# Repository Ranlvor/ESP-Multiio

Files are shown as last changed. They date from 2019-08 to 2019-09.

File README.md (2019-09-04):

Mechanical
==========

Achtung: Eines der Haltelöscher ist nicht 5mm / 5mm vom Rand entfernt! Das 3D-Druck-Gehäuse geht davon aus, dass alle Löscher 5mm/5mm vom Rand entfernt sind und muss noch angepasst werden.

BOM
===

zwingend Nötig
--------------

Bezeichnung | Beschreibung
------------|--------------
U1          | Wemos D1 Mini

notwendig für LEDs und Schalter
-------------------------------

Bezeichnung                    | Beschreibung                        | Package
-------------------------------|-------------------------------------|-----------------
D1, D2, D3, D4, D5, D6, D7, D8 | LEDs                                | 3mm Through Hole
R1, R2, R3, R4, R5, R6, R7, R8 | Vorwiderstände passend zu den LEDs  | 1206 SMD
U2                             | MCP23017                            | DIP-28
C1                             | Kondensator ca. 100 nF              | 1206 SMD

notwendig für IR receive (getestet, hat nicht funktioniert)
-----------------------------------------------------------

Bezeichnung | Beschreibung                        | Package
------------|-------------------------------------|-----------------
U4          | TL1838                              | TSOP1838
C2          | Kondensator ca. 100 nF              | 1206 SMD
R11         | Widerstand 33 kΩ                    | 1206 SMD
R12         | Widerstand 100 Ω                    | 1206 SMD

notwendig für IR send (ungetestet)
----------------------------------

Bezeichnung | Beschreibung                        | Package
------------|-------------------------------------|-----------------
D-IR1       | IR-LED                              | 3mm Through Hole
Q1          | NPN-Transistor (z.B. BC337)         | TO-92
R10         | Widerstand 53 Ω                     | 1206 SMD
R9          | Widerstand 2.1 kΩ                   | 1206 SMD

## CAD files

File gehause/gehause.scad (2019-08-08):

 
tolerance = 0.3;
layer_hight = 0.2;
epsilon = 0.001;
inf = 100;

roundingRadius = 2;
boardX = 75;
boardY = 68;
boardZ = 1.6;
spaceTop = 15;
spaceBottom = 5;

bottomThickness = 3;
topBottomSplit = 5;
margin = 7;
cableDiameter = 4+2*tolerance;
washerDiameter = 7+2*tolerance;
washerHeight = 1;
screwHeadHeight = 5;
connectionDiameter = 7;
connectionHeight = 2;
cornerOnly = 0;
screwHoleDepth = washerHeight + screwHeadHeight + 6;

cutMode = 0;

mode = [
      0, //top normal Mode
      0, //top infill Mode
      0, //top support block Mode
      0, //top text Mode
      1, //bottom normal mode
      0, //bottom infill mode
];
//$fn = 96;
//$fn=10;

module switch() {
 difference() {
  union() {
    cylinder(h=9,d=6+2*tolerance);
    translate([0,0,9-5]) {
        cylinder(h=1+tolerance,d=12+2*tolerance);
        translate([10/2, -2.5/2-tolerance, -1]) cube([4,2.5+2*tolerance,2+tolerance]);
    };
    translate([-13.2/2-tolerance,-7.9/2-tolerance,-9.5-2*tolerance]) cube([13.2+2*tolerance,7.9+2*tolerance,9.5+2*tolerance]);
    
    translate([-1/2,-2/2,-4-9.5-2*tolerance]) cube([1, 2, 4]);
    translate([-1/2+4.7,-2/2,-4-9.5-2*tolerance]) cube([1, 2, 4]);
    translate([-1/2-4.7,-2/2,-4-9.5-2*tolerance]) cube([1, 2, 4]);
    
    //translate([0,0,9]) cylinder(d=3, h=11);
    translate([0,0,9]) rotate([0,12,0]) cylinder(d=3, h=11);
    translate([0,0,9]) rotate([0,-12,0]) cylinder(d=3, h=11);
  }
  translate([0,0,9-5-layer_hight]) cylinder(h=layer_hight,d=6+2*tolerance);
 }
}

module led() {
    translate([0,0,-3]) cylinder(d=3+2*tolerance, h=3);
    translate([0,0,-23]) cylinder(d=4+2*tolerance,h=20);
}
module mountingPole() {
  dia = 7.5;
  difference() {
    hull() {
      translate([0,0,boardZ]) cylinder(d=dia, h=spaceTop-1);
      translate([dia/2,dia/2,boardZ]) cube([4,4,spaceTop-1]);
      translate([-dia/2,dia/2,boardZ]) cube([4,4,spaceTop-1]);
      translate([dia/2,-dia/2,boardZ]) cube([4,4,spaceTop-1]);
    }
    translate([-inf/2,-inf/2,topBottomSplit-inf]) cube([inf,inf,inf]);
  }
  translate([0,0,boardZ]) cylinder(d=dia, h=spaceTop-1);
}


module mountingScrewHole() {
    mountingScrewDiameter = 6;
    mountingScewHeadDiameter = 10;
    hull() {
        translate([0,+mountingScewHeadDiameter/2,-inf/2]) cylinder(h=inf, d=mountingScrewDiameter);
        translate([0,-mountingScewHeadDiameter/2,-inf/2]) cylinder(h=inf, d=mountingScrewDiameter);
    }
    translate([0,-mountingScewHeadDiameter/2,-inf/2]) cylinder(h=inf, d=mountingScewHeadDiameter);
}

module model() {
if(mode[0]) {
  difference() {
    union() {
      difference() {
        hull() {
        translate([-margin,        -margin,        boardZ+spaceTop-roundingRadius]) cylinder(h=roundingRadius, r1=roundingRadius, r2=0);
        translate([boardX+margin,-margin,        boardZ+spaceTop-roundingRadius]) cylinder(h=roundingRadius, r1=roundingRadius, r2=0);
        translate([-margin,        boardY+margin,boardZ+spaceTop-roundingRadius]) cylinder(h=roundingRadius, r1=roundingRadius, r2=0);
        translate([boardX+margin,boardY+margin,boardZ+spaceTop-roundingRadius]) cylinder(h=roundingRadius, r1=roundingRadius, r2=0);
      
        //*
        translate([-margin,        -margin,        topBottomSplit]) cylinder(r=roundingRadius);
        translate([boardX+margin,-margin,        topBottomSplit]) cylinder(r=roundingRadius);
        translate([-margin,        boardY+margin,topBottomSplit]) cylinder(r=roundingRadius);
        translate([boardX+margin,boardY+margin,topBottomSplit]) cylinder(r=roundingRadius); // */
        }
      
  
        translate([-tolerance,-tolerance,-inf+spaceTop-5+boardZ]) cube([boardX+2*tolerance, boardY+2*tolerance, inf]);
        for(i = [0:3]) {
           //switches
          translate([9,13+14*i,10+boardZ+tolerance]) rotate([0,0,180]) switch();
          //leds
          translate([19,13+14*i,boardZ+spaceTop]) led();
          translate([26,13+14*i,boardZ+spaceTop]) led();
        }
        //IR-LED
        translate([boardX-23,boardY-5,boardZ+spaceTop]) led();
      }
      translate([        5,        5,0]) rotate([0,0,180]) mountingPole();
      translate([        5,boardY-5,0]) rotate([0,0, 90]) mountingPole();
      translate([boardX-5,        5,0]) rotate([0,0,-90]) mountingPole();
      translate([boardX-5,boardY-5,0])                  mountingPole();
    }
    translate([        5,        5,0]) cylinder(d=4, h=boardZ+spaceTop-2);
    translate([        5,boardY-5,0]) cylinder(d=4, h=boardZ+spaceTop-2);
    translate([boardX-5,        5,0]) cylinder(d=4, h=boardZ+spaceTop-2);
    translate([boardX-5,boardY-5,0]) cylinder(d=4, h=boardZ+spaceTop-2);
    translate([52, inf+boardX/2, topBottomSplit]) rotate([90,0,0]) cylinder(d=cableDiameter,h=inf);
    
    
    translate([-washerDiameter/2, -washerDiameter/2,topBottomSplit-epsilon]) cylinder(d=connectionDiameter+2*tolerance, h=connectionHeight+tolerance+epsilon);
    translate([washerDiameter/2+boardX,-washerDiameter/2,topBottomSplit-epsilon]) cylinder(d=connectionDiameter+2*tolerance, h=connectionHeight+tolerance+epsilon);
    translate([washerDiameter/2+boardX, washerDiameter/2+boardY,topBottomSplit-epsilon]) cylinder(d=connectionDiameter+2*tolerance, h=connectionHeight+tolerance+epsilon);
    translate([-washerDiameter/2, washerDiameter/2+boardY,topBottomSplit-epsilon]) cylinder(d=connectionDiameter+2*tolerance, h=connectionHeight+tolerance+epsilon);
    
    translate([-washerDiameter/2, -washerDiameter/2,topBottomSplit]) cylinder(d=4, h=boardZ+spaceTop-2-topBottomSplit);
    translate([washerDiameter/2+boardX,-washerDiameter/2,topBottomSplit]) cylinder(d=4, h=boardZ+spaceTop-2-topBottomSplit);
    translate([washerDiameter/2+boardX, washerDiameter/2+boardY,topBottomSplit]) cylinder(d=4, h=boardZ+spaceTop-2-topBottomSplit);
    translate([-washerDiameter/2, washerDiameter/2+boardY,topBottomSplit]) cylinder(d=4, h=boardZ+spaceTop-2-topBottomSplit);
    
    labels();
  }
}

color("green") if(mode[1]){
   hull() {
       translate([10,-10,8+boardZ+tolerance]) rotate([0,0,180]) cylinder(d=15,h=10);
       translate([10,10+boardY,8+boardZ+tolerance]) rotate([0,0,180]) cylinder(d=15,h=10);
   }
   for(i = [0:3]) {
      hull() {
        translate([-10,13+14*i,8+boardZ+tolerance]) rotate([0,0,180]) cylinder(d=15,h=10);
        translate([10,13+14*i,8+boardZ+tolerance]) rotate([0,0,180]) cylinder(d=15,h=10);
        translate([40,13+14*i,8+boardZ+tolerance]) rotate([0,0,180]) cylinder(d=3,h=10);
      }
    }
    translate([52, inf+boardX/2, topBottomSplit]) rotate([90,0,0]) cylinder(d=2*cableDiameter,h=inf);
    
      translate([        5,        5,0])  cylinder(d=8, h=inf);
      translate([        5,boardY-5,0])  cylinder(d=8, h=inf);
      translate([boardX-5,        5,0])  cylinder(d=8, h=inf);
      translate([boardX-5,boardY-5,0])  cylinder(d=8, h=inf);
    
        translate([-washerDiameter/2, -washerDiameter/2,topBottomSplit-epsilon]) cylinder(d=connectionDiameter+2, h=inf);
    translate([washerDiameter/2+boardX,-washerDiameter/2,topBottomSplit-epsilon]) cylinder(d=connectionDiameter+2, h=inf);
    translate([washerDiameter/2+boardX, washerDiameter/2+boardY,topBottomSplit-epsilon]) cylinder(d=connectionDiameter+2, h=inf);
    translate([-washerDiameter/2, washerDiameter/2+boardY,topBottomSplit-epsilon]) cylinder(d=connectionDiameter+2, h=inf);
}

color("red") if(mode[2]) {
    translate([        5,        5,-inf/2]) cylinder(d=4, h=inf);
    translate([        5,boardY-5,-inf/2]) cylinder(d=4, h=inf);
    translate([boardX-5,        5,-inf/2]) cylinder(d=4, h=inf);
    translate([boardX-5,boardY-5,-inf/2]) cylinder(d=4, h=inf);
    
    translate([-washerDiameter/2, -washerDiameter/2,-inf/2]) cylinder(d=4, h=inf);
    translate([washerDiameter/2+boardX,-washerDiameter/2,-inf/2]) cylinder(d=4, h=inf);
    translate([washerDiameter/2+boardX, washerDiameter/2+boardY,-inf/2]) cylinder(d=4, h=inf);
    translate([-washerDiameter/2, washerDiameter/2+boardY,-inf/2]) cylinder(d=4, h=inf);
}

module labels() {
    translate([9,boardY-5,spaceTop+boardZ-1]) linear_extrude(height = 1) text("0 A 1",size=5, halign="center");
    translate([19,boardY-10,spaceTop+boardZ-1]) linear_extrude(height = 1) text("A",size=5, halign="center");
    translate([26,boardY-10,spaceTop+boardZ-1]) linear_extrude(height = 1) text("1",size=5, halign="center");
}
color("white") if(mode[3]) {
    labels();
}
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

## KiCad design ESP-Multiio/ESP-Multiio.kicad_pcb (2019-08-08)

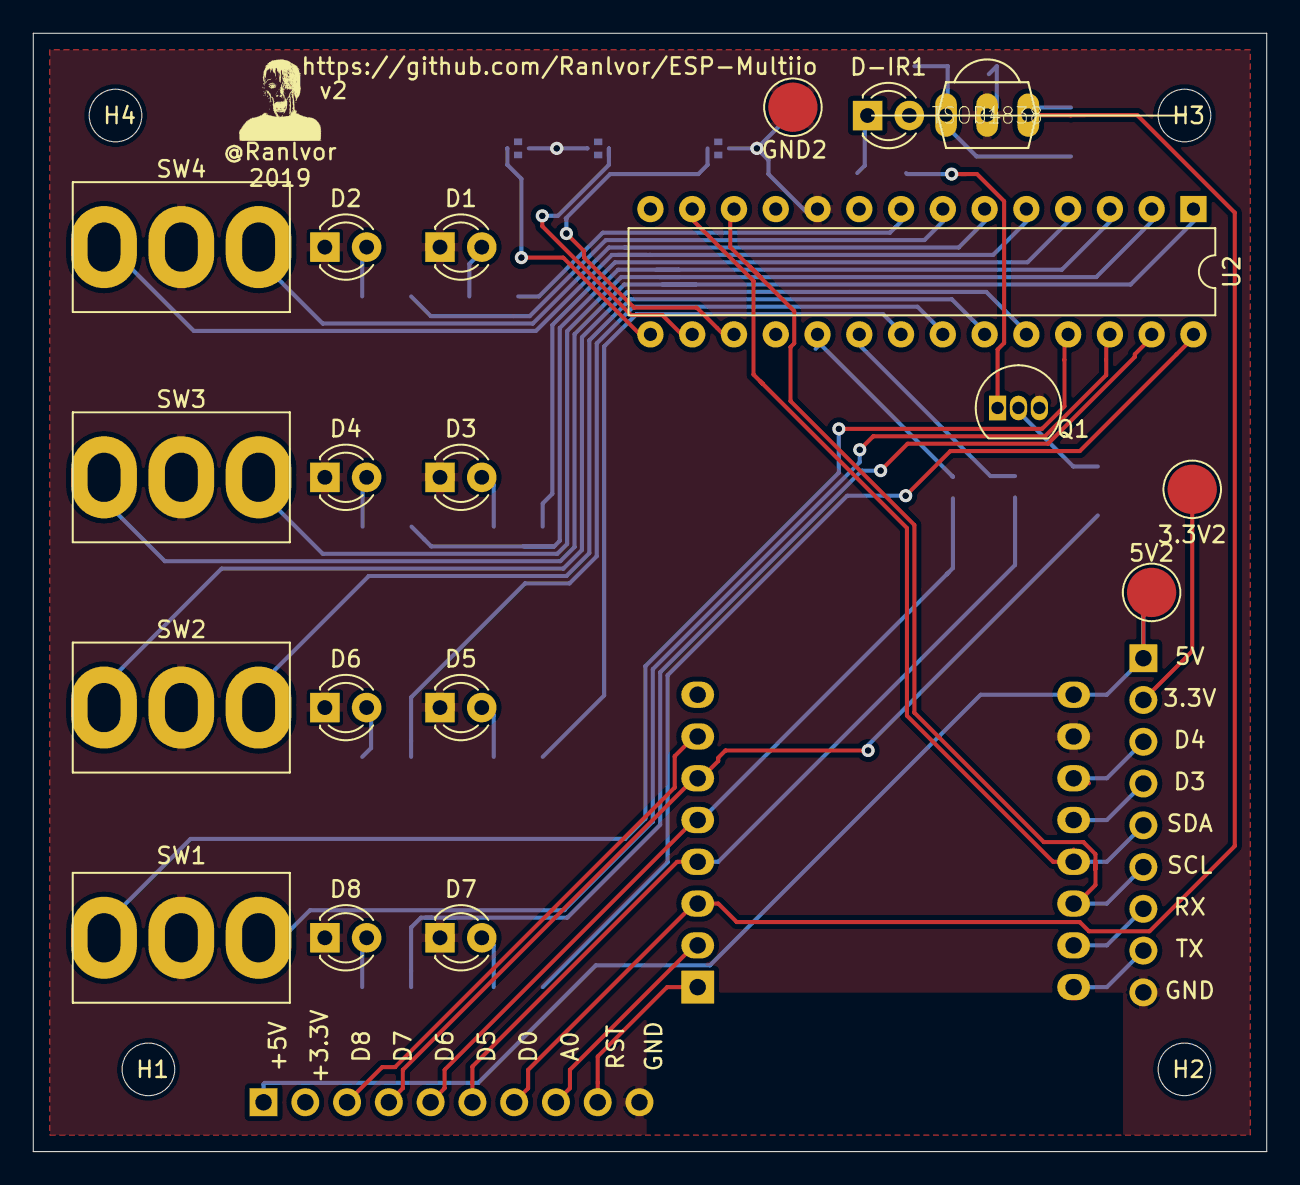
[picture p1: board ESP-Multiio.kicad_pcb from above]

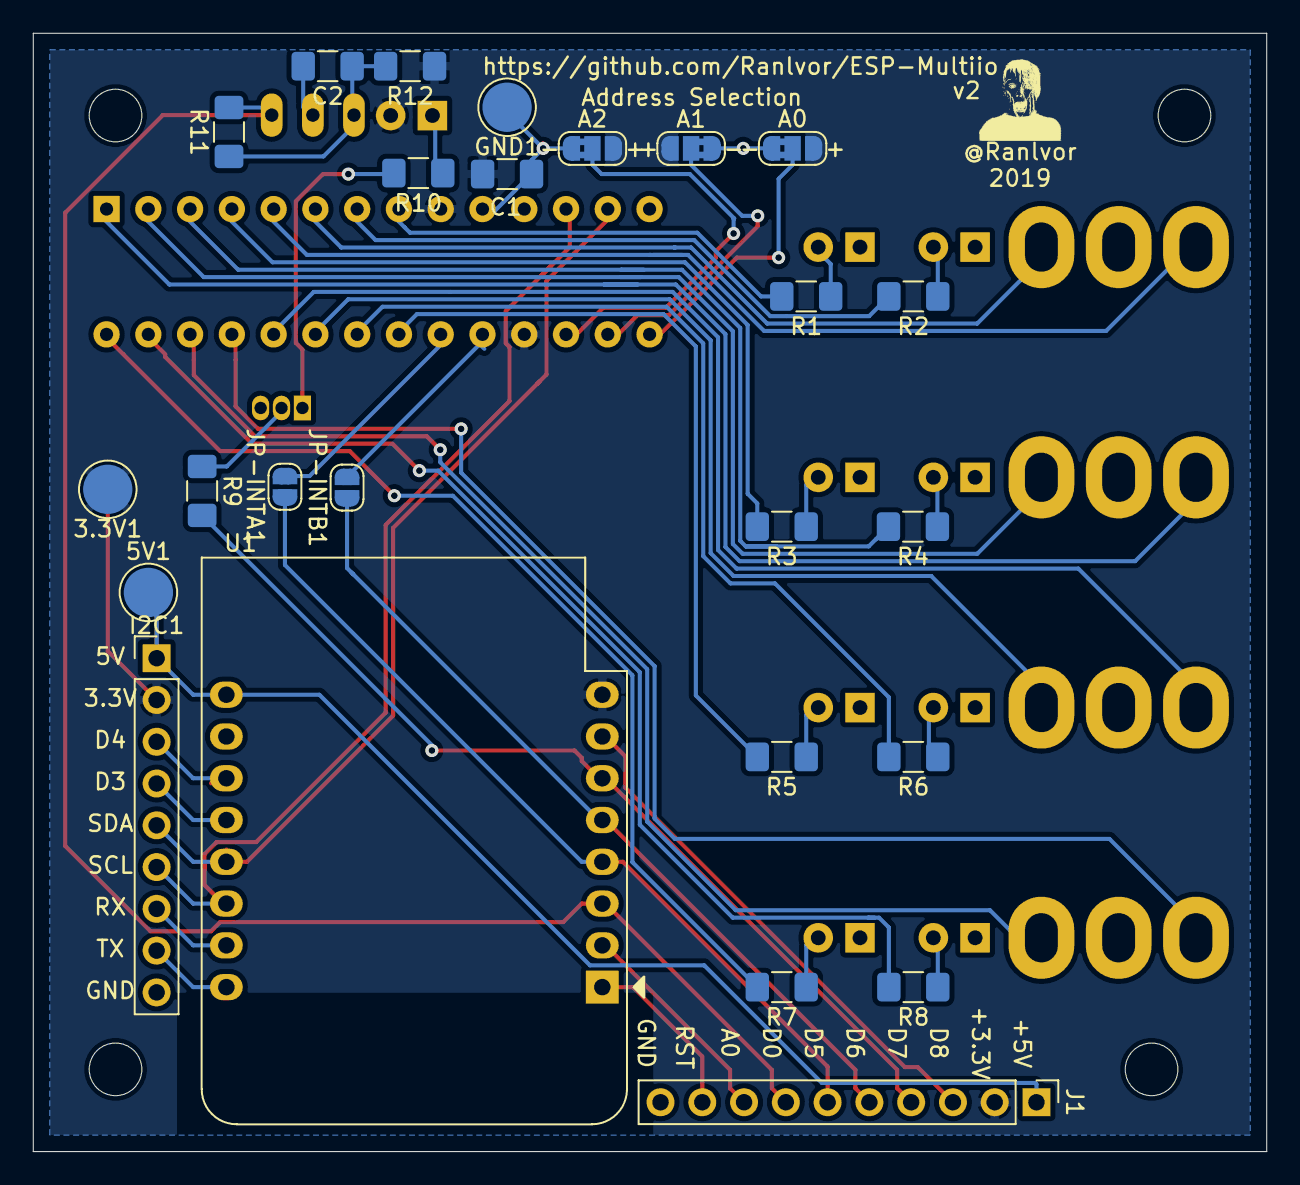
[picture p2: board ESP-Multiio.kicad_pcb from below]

Board: 2 copper layers, 75.0 x 68.0 mm, 48 parts (25 on the bottom side), 49 nets.

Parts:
3.3V1, 3.3V2, 5V1, 5V2: TestPoint; TestPoint_Pad_D3.0mm
A0, A1, A2: SolderJumper; SolderJumper-3_P1.3mm_Bridged2Bar12_RoundedPad1.0x1.5mm_Num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
C1, C2: 100 nF; C_1206_3216Metric_Pad1.42x1.75mm_HandSolder
D1, D2, D3, D4, D5, D6, D7, D8: LED; LED_D3.0mm
D-IR1: LED; LED_D3.0mm
GND1, GND2: TestPoint; TestPoint_Pad_D3.0mm
H1, H2, H3, H4: MountingHole; MountingHole_3.2mm_M3
I2C1: Conn_01x09; PinHeader_1x09_P2.54mm_Vertical
J1: Conn_01x10; PinHeader_1x10_P2.54mm_Vertical
JP-INTA1: SolderJumper_2_Open; SolderJumper-2_P1.3mm_Open_RoundedPad1.0x1.5mm
JP-INTB1: SolderJumper_2_Open; SolderJumper-2_P1.3mm_Open_RoundedPad1.0x1.5mm
Q1: BC337; TO-92_Inline
R1, R2, R3, R4, R5, R6, R7, R8: R; R_1206_3216Metric_Pad1.42x1.75mm_HandSolder
R9: 2.1kΩ; R_1206_3216Metric_Pad1.42x1.75mm_HandSolder
R10: 53 Ω; R_1206_3216Metric_Pad1.42x1.75mm_HandSolder
R11: 33 kΩ; R_1206_3216Metric_Pad1.42x1.75mm_HandSolder
R12: 100Ω; R_1206_3216Metric_Pad1.42x1.75mm_HandSolder
SW1, SW2, SW3, SW4: SW_SPDT_MSM; MTS-103
U1: WeMos_D1_mini; WEMOS_D1_mini_light
U2: MCP23017_SP; DIP-28_W7.62mm
U4: TSOP1838; TSOP18XX

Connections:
+3V3: 3.3V1.1, 3.3V2.1, A0.3, A1.3, A2.3, C1.1, D-IR1.2, I2C1.2, J1.2, R12.1, U1.8, U2.9, U2.18
+5V: 5V1.1, 5V2.1, I2C1.1, J1.1, U1.9
/A0: J1.8, U1.2
/D0: J1.7, R11.2, U1.3, U4.OUT
/D5: J1.6, JP-INTA1.1, U1.4
/D6: J1.5, JP-INTB1.1, U1.5
/D7: J1.4, R9.2, U1.6
/D8: J1.3, U1.7
/GPA0: R1.2, U2.8
/GPA1: R2.2, U2.7
/GPA2: SW4.1, U2.6
/GPA3: SW4.3, U2.5
/GPA4: R3.2, U2.4
/GPA5: R4.2, U2.3
/GPA6: SW3.1, U2.2
/GPA7: SW3.3, U2.1
/GPB0: R7.2, U2.28
/GPB1: R8.2, U2.27
/GPB2: SW1.1, U2.26
/GPB3: SW1.3, U2.25
/GPB4: SW2.3, U2.24
/GPB5: SW2.1, U2.23
/GPB6: R6.2, U2.22
/GPB7: R5.2, U2.21
/RST: J1.9, U1.1
/RX: I2C1.7, U1.15
/TX: I2C1.8, U1.16
D3: I2C1.4, U1.12
D4: I2C1.3, U1.11
GND: A0.1, A1.1, A2.1, C1.2, C2.2, D1.1, D2.1, D3.1, D4.1, D5.1, D6.1, D7.1, D8.1, GND1.1, GND2.1, I2C1.9, J1.10, Q1.3, SW1.2, SW2.2, SW3.2, SW4.2, U1.10, U2.10, U4.GND
unnamed: A0.2, U2.15
unnamed: A1.2, U2.16
unnamed: A2.2, U2.17
unnamed: C2.1, R11.1, R12.2, U4.VCC
unnamed: D1.2, R1.1
unnamed: D2.2, R2.1
unnamed: D3.2, R3.1
unnamed: D4.2, R4.1
unnamed: D5.2, R5.1
unnamed: D6.2, R6.1
unnamed: D7.2, R7.1
unnamed: D8.2, R8.1
unnamed: D-IR1.1, R10.1
unnamed: JP-INTA1.2, U2.20
unnamed: JP-INTB1.2, U2.19
unnamed: Q1.1, R10.2
unnamed: Q1.2, R9.1
SCL: I2C1.6, U1.14, U2.12
SDA: I2C1.5, U1.13, U2.13

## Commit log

2019-06-07 Better switch-footprint, add twitter avatar, add github link
    [ESP-Multiio.kicad_pcb, ESP-Multiio.sch]
2019-06-08 more 3.3V fill
    [ESP-Multiio.kicad_pcb]
2019-06-10 Change board dimensions
    Because the switches need to be further appart
    [ESP-Multiio.kicad_pcb, ESP-Multiio.sch]
2019-06-10 Mechanical Details, Mechanical data in Silkscreen
    [ESP-Multiio.kicad_pcb]
2019-06-10 More fill
    [ESP-Multiio.kicad_pcb]
2019-06-15 Add gerber code, more gehäuse-stuff
    [ESP-Multiio-B_Cu.gbr, ESP-Multiio-B_Mask.gbr, ESP-Multiio-B_Paste.gbr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]
2019-06-16 Gehäuse: Add Bottom part
    [gehause.scad]
2019-06-19 First Version of Gehäuse
    [gehause.scad]
2019-06-19 After first testprint: put in screw deeper because my screws are a bit short
    [gehause.scad]
2019-06-22 Add flatmode
    [gehause.scad]
2019-06-22 Fix wiring in flat mode
    The cable has to go on top of the board in flat mode instead of below the board
    [gehause.scad]
2019-07-05 allow rendering cuts of the gehäuse
    [gehause.scad]
2019-07-05 Further gehäuse cut improvements
    - rotate cut to fit preview
    - higher resolution
    - top/bottom-combination-view
    [gehause.scad]
2019-07-05 one layer of plastic in switch screw hole
    to make it printable without support
    [gehause.scad]
2019-07-05 Deeper screw holes
    to allow us to use the shorter screw
    [gehause.scad]
2019-07-05 lower the text into the surface
    to get a flat surface to be able to print it
    [gehause.scad]
2019-07-07 chamfers on the top instead of fillets
    because current plan is to print the top face down and that does not work with fillets.
    [gehause.scad]
2019-07-07 Weniger rundung
    weil zu viel rundung mit chamfers einfach kacke aussieht
    [gehause.scad]
2019-07-12 Add IR sender LED
    [gehause.scad]
2019-08-08 Flip two parts on board to lower casing hight
    [ESP-Multiio.kicad_pcb]
2019-08-08 generate gerber v2
    [ESP-Multiio-B_Cu.gbr, ESP-Multiio-B_Mask.gbr, ESP-Multiio-B_Paste.gbr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]
2019-08-08 remove non-flat-mode-support
    [gehause.scad]
2019-08-08 reduce spaceBottom
    The big transistor is gone, we just need 5 mm for the capacitors and the mounting screws
    [gehause.scad]
